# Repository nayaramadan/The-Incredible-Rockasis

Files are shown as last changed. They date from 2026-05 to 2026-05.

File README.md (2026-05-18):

# The-Incredible-Rockasis
CANClean is a roverthat finds, targets and, grabs empty soda cans. I t does this in order to keep your workspace clean and (less)messy.
# Pipeline
An ESP32-CAM takes live camera views and streams them via a TP-Link router(our Stasis Stash item) to my laptop where they are then sent out to roboflow for inference. After inference, the relative position of the can to the rover is calculted by my laptop andthe approach angle and vector are formed. The latop then sends these backto the rover where an Opheus Pico contols the motors to execute the vectors. The laptop then uses the sonar sensor and the camera to detect when the can is inside the claw. Then it closes.
# Demo
Demo
# Images
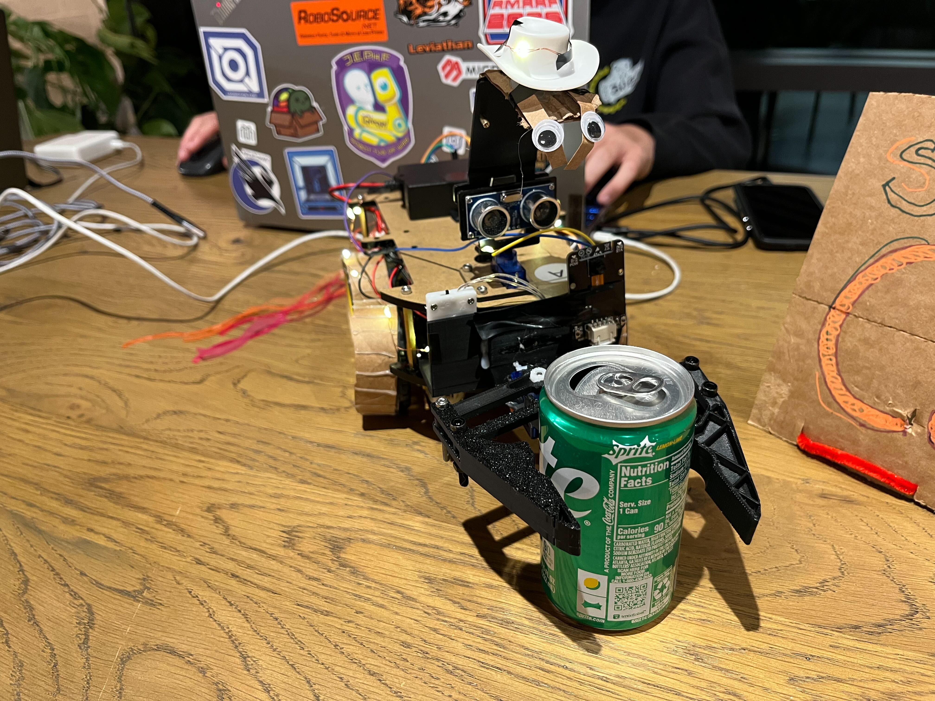
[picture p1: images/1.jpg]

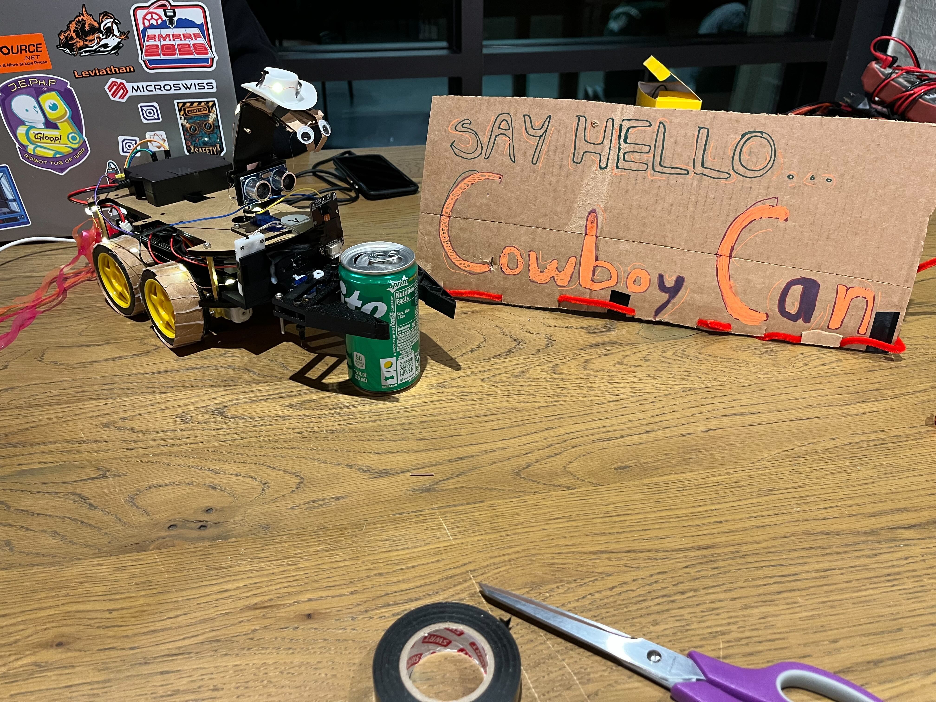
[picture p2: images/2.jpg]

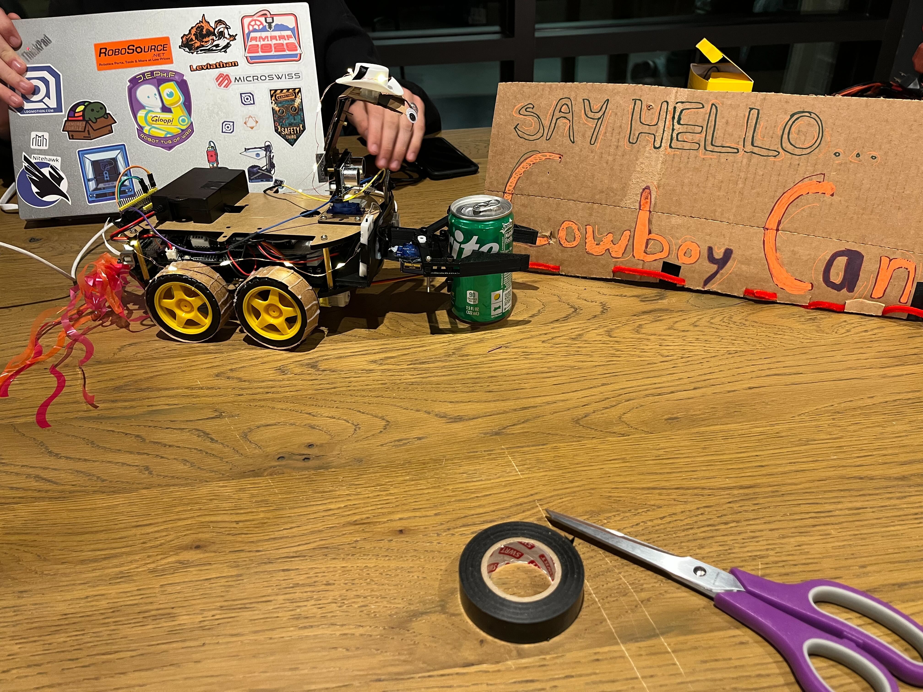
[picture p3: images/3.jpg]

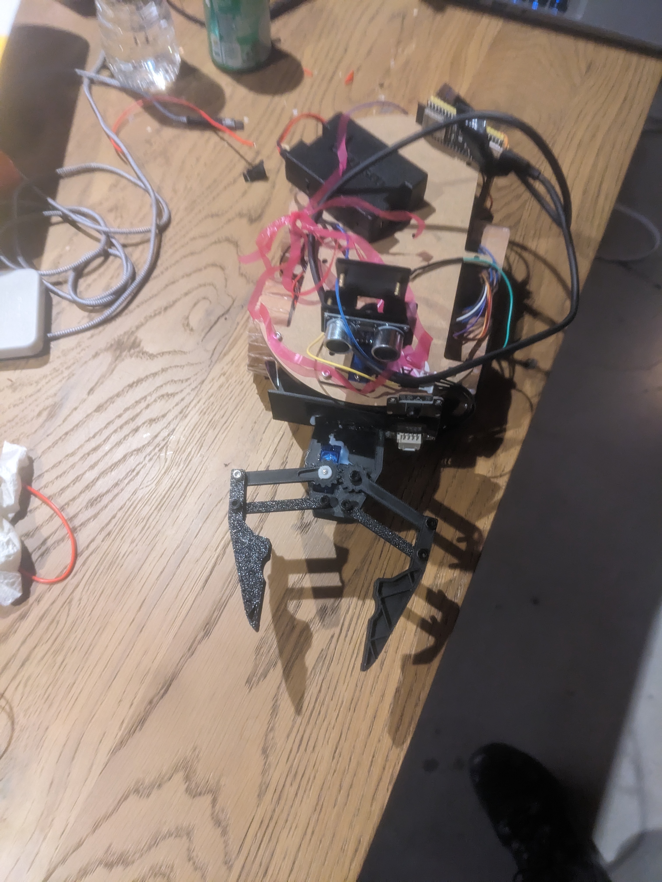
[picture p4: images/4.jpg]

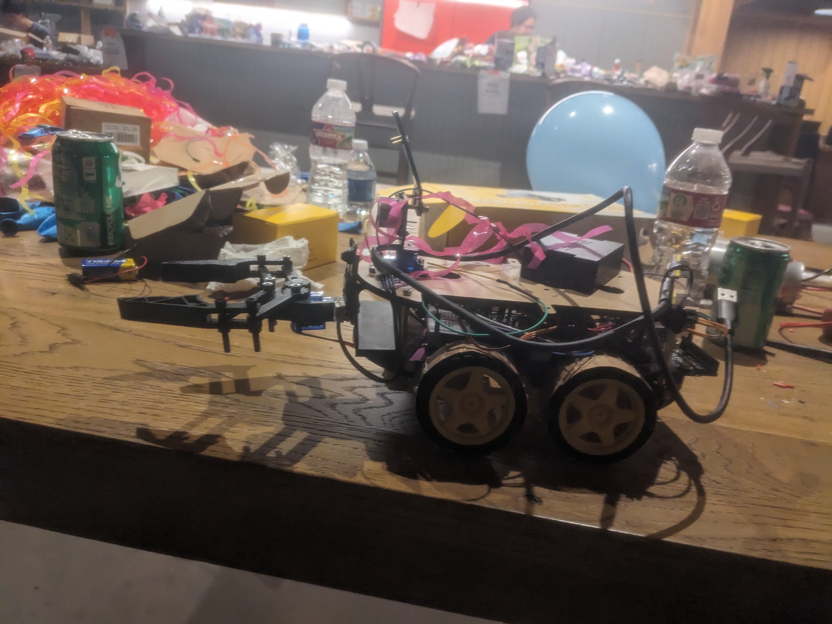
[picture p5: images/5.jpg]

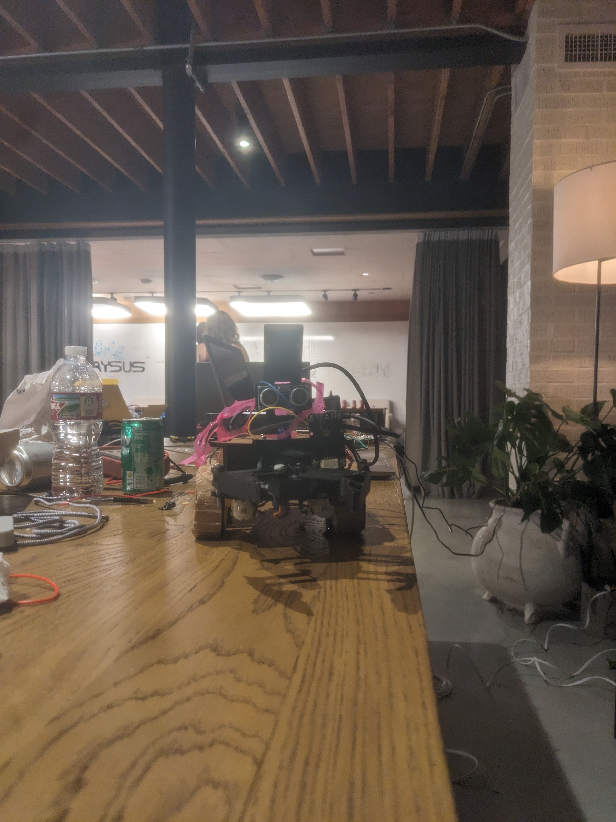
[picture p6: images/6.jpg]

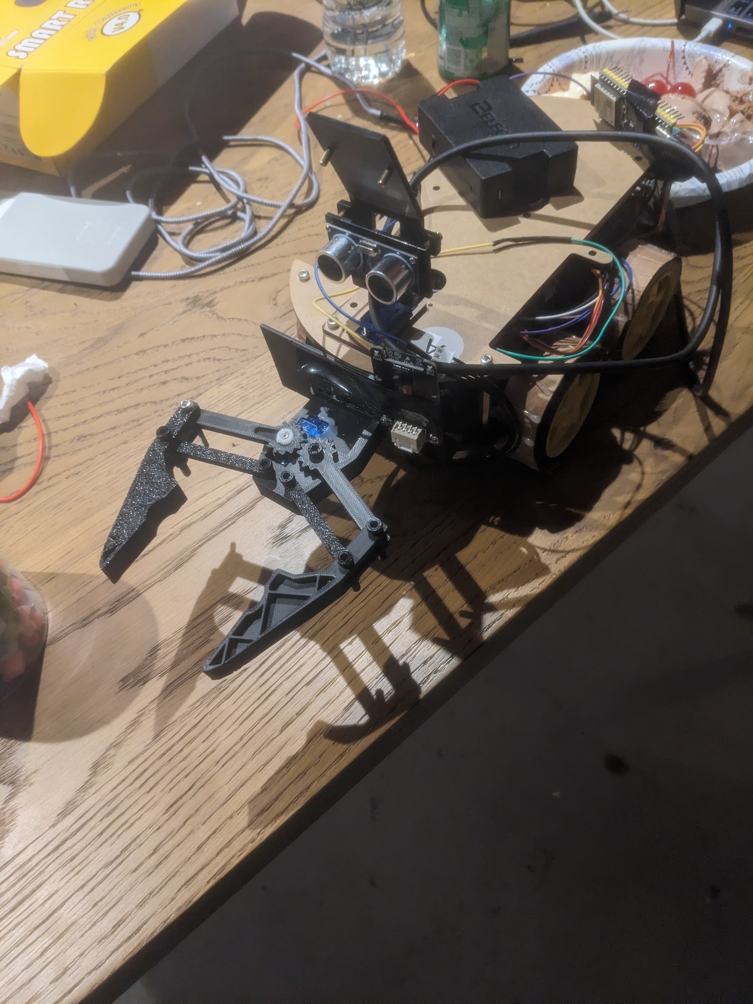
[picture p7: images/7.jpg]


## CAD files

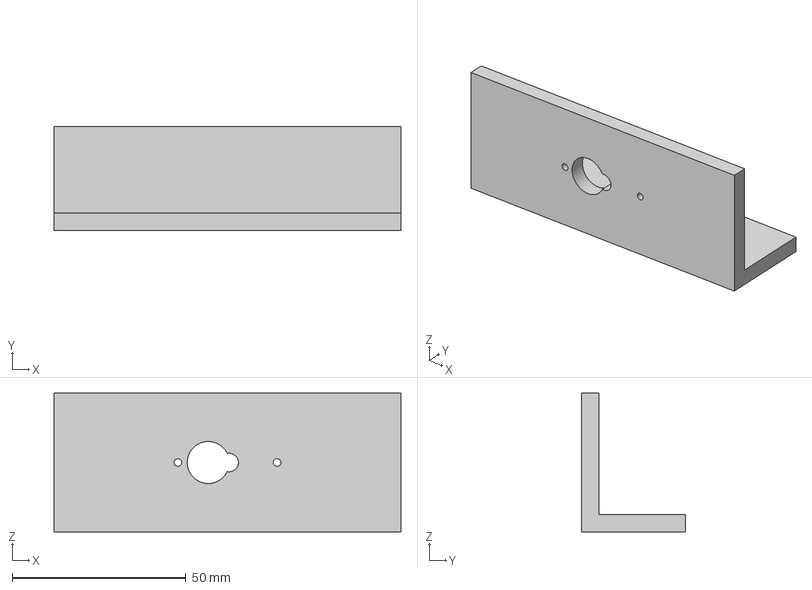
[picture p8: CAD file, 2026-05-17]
Body1.3mf
100.0 x 30.0 x 40.0 mm

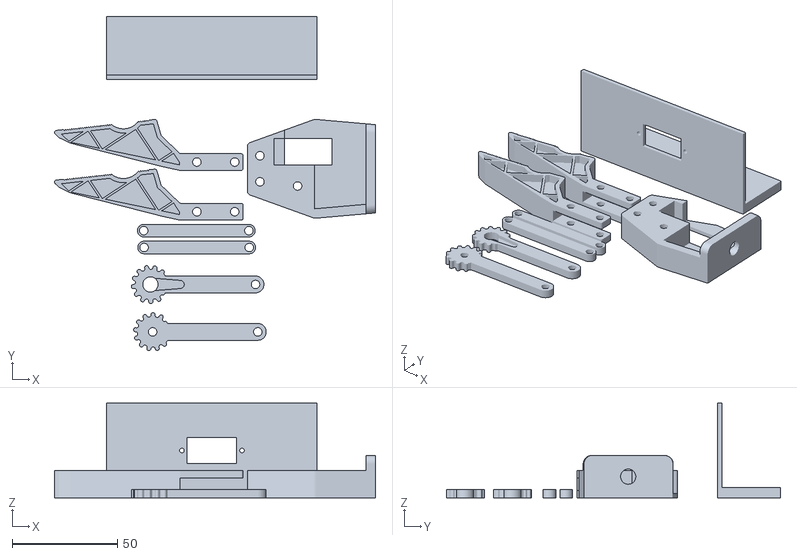
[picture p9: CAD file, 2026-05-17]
CAD/Base.stl
152.6 x 159.0 x 45.0

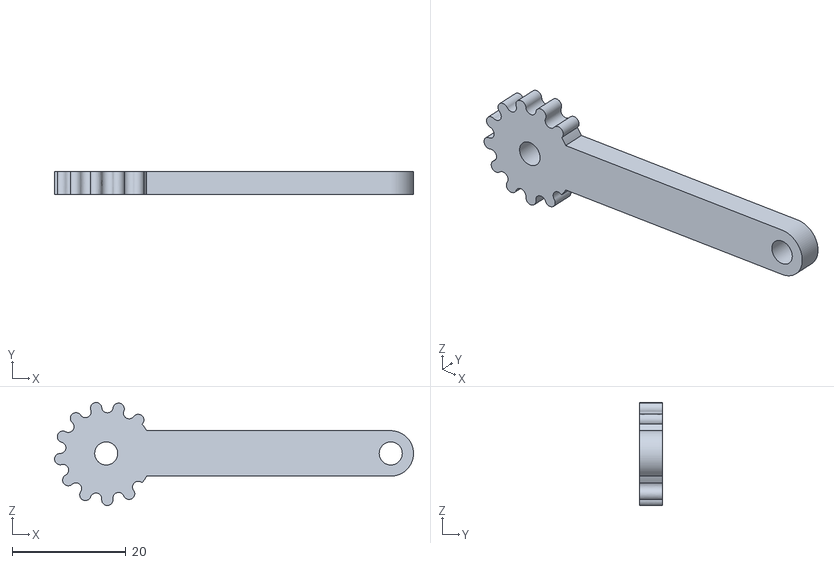
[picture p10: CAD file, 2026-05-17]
CAD/claw/Connector_Gear.stl
63.1 x 4.00 x 18.1

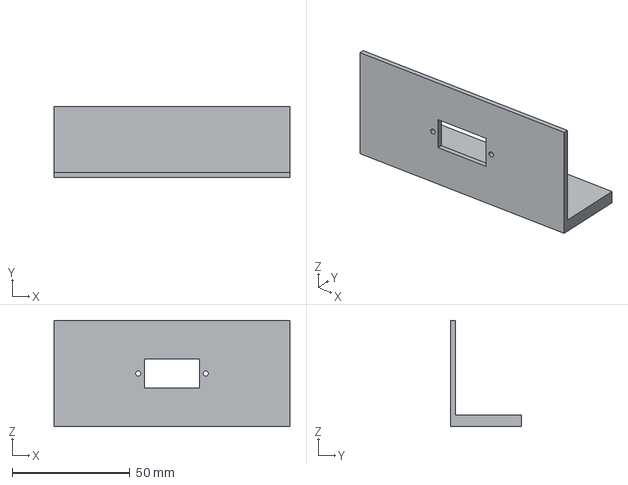
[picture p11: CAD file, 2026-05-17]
CAD/mount-Body.step
100.0 x 30.0 x 45.0 mm

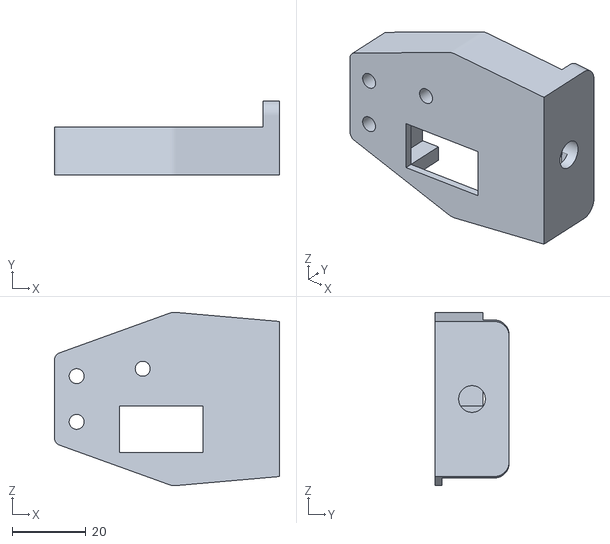
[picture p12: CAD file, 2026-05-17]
CAD/claw/Base.stl
60.9 x 20.1 x 46.9

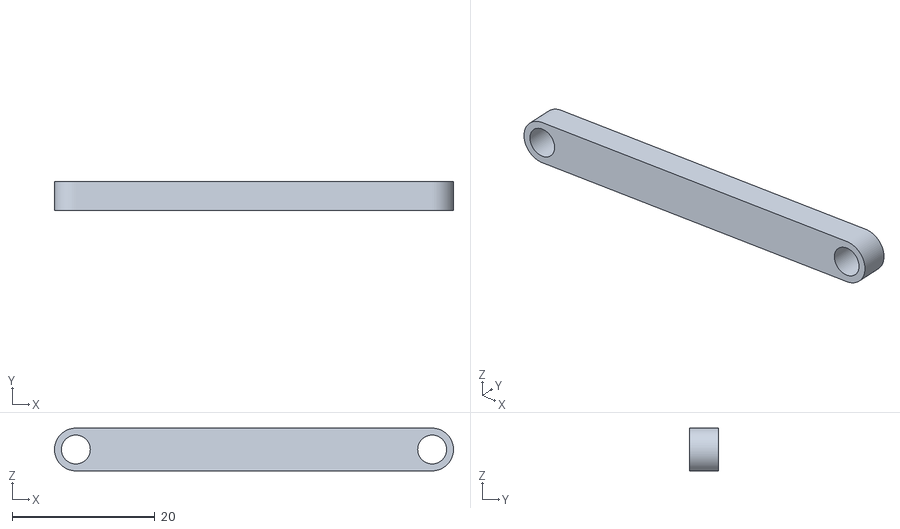
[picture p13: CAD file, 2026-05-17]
CAD/claw/Connector.stl
56.0 x 4.00 x 6.00

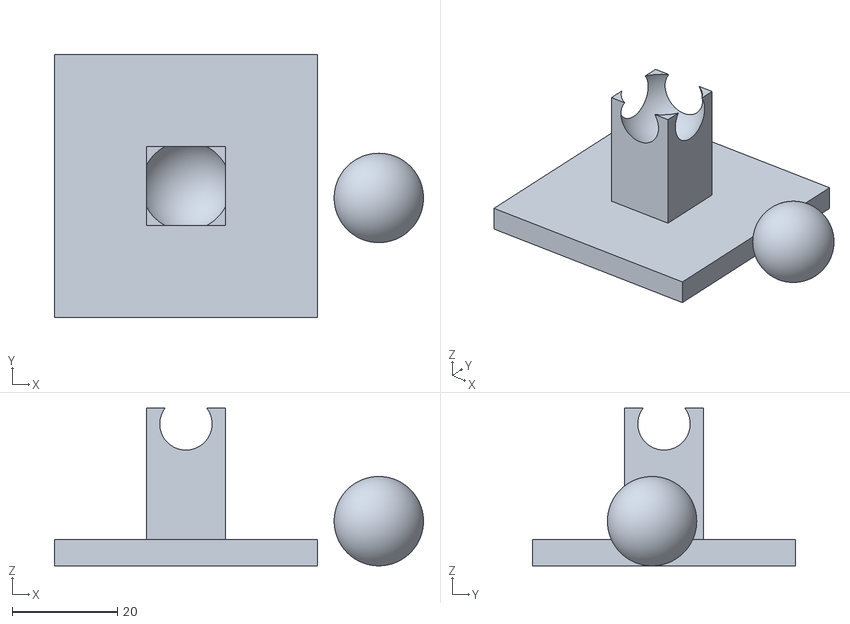
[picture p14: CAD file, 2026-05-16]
CAD/roller-and-mount.stl
70.2 x 50.0 x 30.0

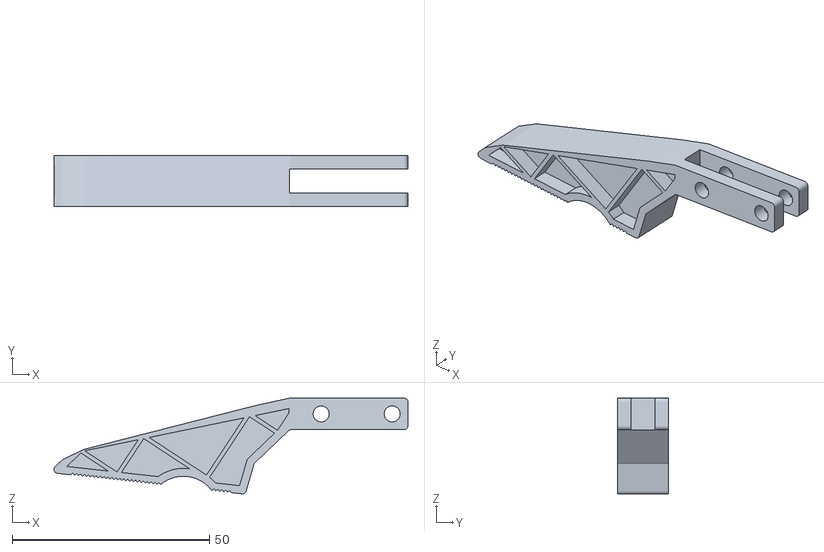
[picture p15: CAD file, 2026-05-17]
CAD/claw/Claw.stl
89.7 x 12.9 x 24.3

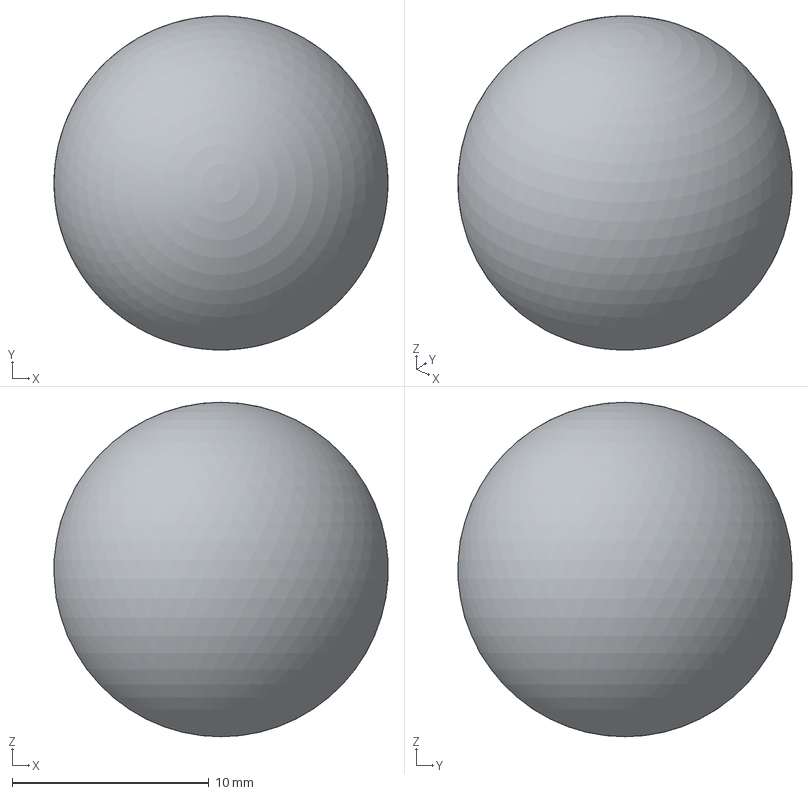
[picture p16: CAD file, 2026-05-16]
CAD/roller-Body.step
17.0 x 17.0 x 17.0 mm

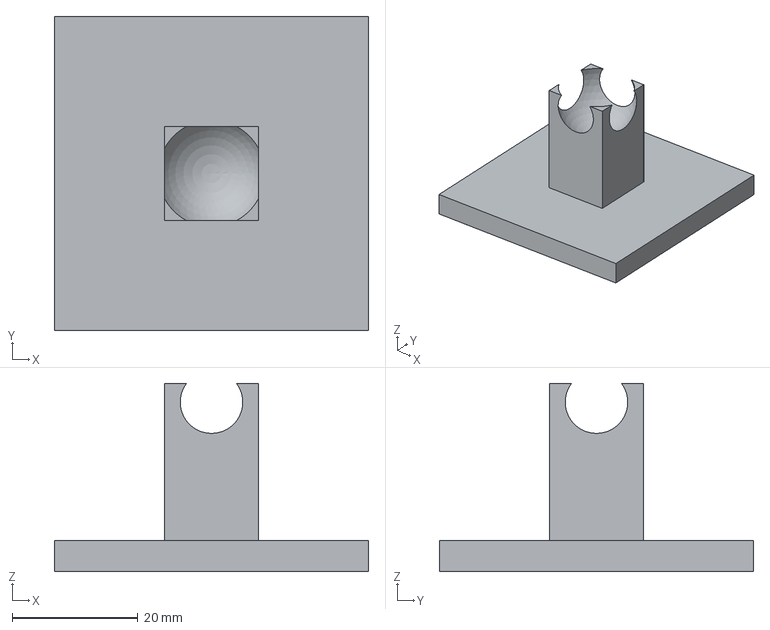
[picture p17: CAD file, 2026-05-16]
CAD/roller-mount-Body.step
50.0 x 50.0 x 30.0 mm

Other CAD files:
CAD/claw/Servo_Connector_Gear.stl
CAD/mount.FCStd

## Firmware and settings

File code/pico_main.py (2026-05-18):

"""
pico_main.py  –  Orpheus Pico (RP2040) rover firmware
======================================================
Responsibilities
  • Read MPU-6050 over I²C → complementary-filter roll/pitch/yaw
  • Drive 4× DC motors via TB6612FNG (2 ICs, 4 channels)
  • Control servo claw via hardware PWM
  • Receive COBS-framed command packets from ESP32-S3 over UART1
  • Send COBS-framed telemetry packets back to ESP32-S3

Wiring (edit PIN constants below to match your board)
─────────────────────────────────────────────────────
I²C (MPU-6050)
  SDA  → GP4      SCL → GP5      (I2C0)

UART (ESP32-S3)
  TX   → GP8      RX  → GP9      (UART1)  921600 baud

Single TB6612FNG motor driver
  STBY → GP16
  PWMA → GP10     AIN1 → GP11    AIN2 → GP12   (left motors – both wired to channel A)
  PWMB → GP13     BIN1 → GP14    BIN2 → GP15   (right motors – both wired to channel B)

Servo 1 (claw open/close)
  PWM  → GP28

Servo 2 (claw tilt / wrist)
  PWM  → GP27

Servo 3 (sonar yaw pan)
  PWM  → GP26

HC-SR04 (single sonar, direct to Pico)
  TRIG → GP19    ECHO → GP20
  ECHO needs a 1 kΩ/2 kΩ divider to 3.3 V if using a 5 V sensor board
"""

import struct
import time
import math
from machine import I2C, UART, Pin, PWM

# ─── Pin constants ────────────────────────────────────────────────────────────

I2C_SDA   = 4
I2C_SCL   = 5

UART_TX   = 8
UART_RX   = 9
UART_BAUD = 921600

# Single TB6612FNG
# Channel A → both left motors  (front-left + rear-left wired in parallel)
# Channel B → both right motors (front-right + rear-right wired in parallel)
M_STBY = 16
M_PWMA = 10
M_AIN1 = 11
M_AIN2 = 12
M_PWMB = 13
M_BIN1 = 14
M_BIN2 = 15

SERVO_PIN  = 28   # claw open/close
SERVO2_PIN = 27   # claw tilt / wrist
SERVO3_PIN = 26   # sonar yaw pan

# HC-SR04 (single, connected directly to Pico)
SONAR_TRIG = 19
SONAR_ECHO = 20
SONAR_TIMEOUT_US = 30_000   # 30 ms → ~5 m max range

# ─── MPU-6050 ─────────────────────────────────────────────────────────────────

MPU_ADDR  = 0x68
PWR_MGMT1 = 0x6B
ACCEL_OUT = 0x3B   # 6 bytes: AX_H AX_L AY_H AY_L AZ_H AZ_L
GYRO_OUT  = 0x43   # 6 bytes: GX_H GX_L GY_H GY_L GZ_H GZ_L
GYRO_CFG  = 0x1B   # ±250 °/s  → sensitivity 131 LSB/(°/s)
ACCEL_CFG = 0x1C   # ±2 g      → sensitivity 16384 LSB/g

GYRO_SENS  = 131.0
ACCEL_SENS = 16384.0

class MPU6050:
    def __init__(self, i2c):
        self.i2c = i2c
        # Wake the chip
        self.i2c.writeto_mem(MPU_ADDR, PWR_MGMT1, bytes([0x00]))
        time.sleep_ms(100)
        # Set gyro ±250 °/s, accel ±2 g
        self.i2c.writeto_mem(MPU_ADDR, GYRO_CFG,  bytes([0x00]))
        self.i2c.writeto_mem(MPU_ADDR, ACCEL_CFG, bytes([0x00]))

    def _read_raw(self, reg):
        raw = self.i2c.readfrom_mem(MPU_ADDR, reg, 6)
        vals = struct.unpack(">3h", raw)   # three signed 16-bit big-endian
        return vals

    def read_accel_g(self):
        ax, ay, az = self._read_raw(ACCEL_OUT)
        return ax / ACCEL_SENS, ay / ACCEL_SENS, az / ACCEL_SENS

    def read_gyro_dps(self):
        gx, gy, gz = self._read_raw(GYRO_OUT)
        return gx / GYRO_SENS, gy / GYRO_SENS, gz / GYRO_SENS


class ComplementaryFilter:
    """Simple roll/pitch/yaw complementary filter.
    Yaw integrates gyro only (no magnetometer), so it drifts slowly.
    """
    ALPHA = 0.96   # weight for gyro vs accel

    def __init__(self):
        self.roll  = 0.0
        self.pitch = 0.0
        self.yaw   = 0.0
        self._last_us = time.ticks_us()

    def update(self, ax, ay, az, gx, gy, gz):
        now = time.ticks_us()
        dt  = time.ticks_diff(now, self._last_us) * 1e-6
        self._last_us = now

        # Accel-derived angles
        roll_acc  = math.atan2(ay, az) * 57.2958
        pitch_acc = math.atan2(-ax, math.sqrt(ay*ay + az*az)) * 57.2958

        # Complementary blend
        self.roll  = self.ALPHA * (self.roll  + gx * dt) + (1 - self.ALPHA) * roll_acc
        self.pitch = self.ALPHA * (self.pitch + gy * dt) + (1 - self.ALPHA) * pitch_acc
        self.yaw  += gz * dt   # gyro-only; reset to 0 on boot

        return self.roll, self.pitch, self.yaw


# ─── Motor driver ─────────────────────────────────────────────────────────────

PWM_FREQ = 20_000   # 20 kHz – above audible range

class MotorChannel:
    """One half-bridge channel on a TB6612FNG."""
    def __init__(self, pwm_pin, in1_pin, in2_pin):
        self.pwm = PWM(Pin(pwm_pin), freq=PWM_FREQ, duty_u16=0)
        self.in1 = Pin(in1_pin, Pin.OUT)
        self.in2 = Pin(in2_pin, Pin.OUT)

    def set(self, speed: float):
        """speed: -1.0 … +1.0"""
        speed = max(-1.0, min(1.0, speed))
        duty  = int(abs(speed) * 65535)
        self.pwm.duty_u16(duty)
        if speed > 0:
            self.in1.value(1); self.in2.value(0)
        elif speed < 0:
            self.in1.value(0); self.in2.value(1)
        else:
            self.in1.value(0); self.in2.value(0)   # coast

    def brake(self):
        self.pwm.duty_u16(65535)
        self.in1.value(1); self.in2.value(1)


class RoverMotors:
    """
    Single TB6612FNG, two channels:
      Channel A → left side  (front-left + rear-left motors in parallel)
      Channel B → right side (front-right + rear-right motors in parallel)
    """
    def __init__(self):
        self.stby  = Pin(M_STBY, Pin.OUT, value=0)
        self.left  = MotorChannel(M_PWMA, M_AIN1, M_AIN2)
        self.right = MotorChannel(M_PWMB, M_BIN1, M_BIN2)
        self.enable()

    def enable(self):
        self.stby.value(1)

    def disable(self):
        self.stby.value(0)

    def drive(self, throttle: float, steering: float):
        """
        throttle: -1.0 (full reverse) … +1.0 (full forward)
        steering: -1.0 (full left)    … +1.0 (full right)
        Uses differential/tank mixing.
        """
        left  = max(-1.0, min(1.0, throttle - steering))
        right = max(-1.0, min(1.0, throttle + steering))
        self.left.set(left)
        self.right.set(right)

    def stop(self):
        self.left.set(0.0)
        self.right.set(0.0)


# ─── Servo ────────────────────────────────────────────────────────────────────

SERVO_FREQ      = 50          # 50 Hz = 20 ms period
SERVO_MIN_US    = 1000        # 1 ms  → fully open
SERVO_MAX_US    = 2000        # 2 ms  → fully closed
SERVO_CENTER_US = 1500

class ServoClaw:
    def __init__(self, pin):
        self.pwm = PWM(Pin(pin), freq=SERVO_FREQ)
        self.set(0.0)          # start centred / open

    def _us_to_duty(self, us):
        # RP2040 PWM period = 1/50 = 20 000 µs → 65535 counts
        return int(us / 20_000 * 65535)

    def set(self, pos: float):
        """pos: 0.0 = open, 1.0 = closed"""
        pos = max(0.0, min(1.0, pos))
        us  = int(SERVO_MIN_US + pos * (SERVO_MAX_US - SERVO_MIN_US))
        self.pwm.duty_u16(self._us_to_duty(us))

    def open(self):  self.set(0.0)
    def close(self): self.set(1.0)


# ─── HC-SR04 sonar ────────────────────────────────────────────────────────────

from machine import time_pulse_us

class HCSR04:
    """Single HC-SR04 ultrasonic sensor."""
    def __init__(self, trig_pin, echo_pin):
        self.trig = Pin(trig_pin, Pin.OUT, value=0)
        self.echo = Pin(echo_pin, Pin.IN)

    def distance_mm(self) -> int:
        """Returns distance in mm, or -1 on timeout / no echo."""
        self.trig.value(0)
        time.sleep_us(2)
        self.trig.value(1)
        time.sleep_us(10)
        self.trig.value(0)
        duration = time_pulse_us(self.echo, 1, SONAR_TIMEOUT_US)
        if duration < 0:
            return -1
        return int(duration * 0.1715)   # mm = µs × (343 000 mm/s / 2 / 1 000 000)


class SonarPan:
    """
    Combines the HC-SR04 with servo3 to sweep the sonar.
    Call update() every loop tick; it steps the servo and fires
    a ping at each position, building a simple scan buffer.
    """
    POSITIONS  = [0.0, 0.25, 0.5, 0.75, 1.0]   # 5 pan angles
    DWELL_MS   = 60    # ms to wait after moving before pinging

    def __init__(self, sonar: HCSR04, pan_servo: 'ServoClaw'):
        self.sonar     = sonar
        self.servo     = pan_servo
        self._idx      = 0
        self._moved_at = 0
        self._readings = [-1] * len(self.POSITIONS)
        # Move to first position immediately
        self.servo.set(self.POSITIONS[0])
        self._moved_at = time.ticks_ms()

    @property
    def readings(self) -> list:
        """Latest distance (mm) for each pan position. -1 = no echo."""
        return list(self._readings)

    @property
    def current_pos(self) -> float:
        """Current servo pan position 0.0–1.0."""
        return self.POSITIONS[self._idx]

    def update(self):
        """Call every loop iteration. Non-blocking step machine."""
        now = time.ticks_ms()
        if time.ticks_diff(now, self._moved_at) < self.DWELL_MS:
            return   # still settling
        # Ping at current position
        self._readings[self._idx] = self.sonar.distance_mm()
        # Advance to next position
        self._idx = (self._idx + 1) % len(self.POSITIONS)
        self.servo.set(self.POSITIONS[self._idx])
        self._moved_at = now


# ─── COBS framing ─────────────────────────────────────────────────────────────
# Consistent Overhead Byte Stuffing – zero-free framing over serial.
# Packet boundary = 0x00 byte.

def cobs_encode(data: bytes) -> bytes:
    out    = bytearray()
    code   = 1
    block  = bytearray()
    for byte in data:
        if byte == 0:
            out.append(code)
            out.extend(block)
            code  = 1
            block = bytearray()
        else:
            block.append(byte)
            code += 1
            if code == 0xFF:
                out.append(code)
                out.extend(block)
                code  = 1
                block = bytearray()
    out.append(code)
    out.extend(block)
    out.append(0x00)   # frame delimiter
    return bytes(out)


def cobs_decode(frame: bytes) -> bytes:
    """frame must NOT include the trailing 0x00 delimiter."""
    out = bytearray()
    i   = 0
    while i < len(frame):
        code = frame[i]
        i   += 1
        for _ in range(code - 1):
            if i >= len(frame):
                raise ValueError("COBS: truncated")
            out.append(frame[i])
            i += 1
        if code < 0xFF and i < len(frame):
            out.append(0x00)
    return bytes(out)


# ─── Packet formats  (little-endian structs) ──────────────────────────────────
#
# CMD packet  (ESP32-S3 → Pico)   10 bytes
#   [0]    packet type  0x01
#   [1]    throttle     int8  (-100 … +100, scale /100 → float)
#   [2]    steering     int8  (-100 … +100)
#   [3]    claw         uint8 (0 … 100)
#   [4]    servo2       uint8 (0 … 100)
#   [5]    servo3       uint8 (0 … 100)  sonar yaw pan
#   [6:10] CRC-32       uint32 LE (over bytes 0-5)
#
# TELEM packet (Pico → ESP32-S3)  20 bytes
#   [0]     packet type  0x02
#   [1:5]   roll         float32 LE
#   [5:9]   pitch        float32 LE
#   [9:13]  yaw          float32 LE
#   [13]    flags        uint8  (bit0=motors_on, bit1=claw_closed)
#   [14:16] sonar_mm     uint16 LE  (0xFFFF = no echo)
#   [16]    sonar_pan    uint8  (0-100, current servo3 position ×100)
#   [17:19] CRC-16       uint16 LE (over bytes 0-16)

CMD_TYPE   = 0x01
TELEM_TYPE = 0x02

def _crc16(data: bytes) -> int:
    crc = 0xFFFF
    for b in data:
        crc ^= b
        for _ in range(8):
            if crc & 1:
                crc = (crc >> 1) ^ 0xA001
            else:
                crc >>= 1
    return crc & 0xFFFF

def build_telem(roll, pitch, yaw, motors_on, claw_closed,
                sonar_mm: int, sonar_pan: float) -> bytes:
    flags    = (1 if motors_on else 0) | (2 if claw_closed else 0)
    sonar_v  = 0xFFFF if sonar_mm < 0 else min(0xFFFE, sonar_mm)
    pan_byte = max(0, min(100, int(sonar_pan * 100)))
    payload  = (struct.pack("<BfffB", TELEM_TYPE, roll, pitch, yaw, flags)
                + struct.pack("<HB", sonar_v, pan_byte))
    crc = _crc16(payload)
    return cobs_encode(payload + struct.pack("<H", crc))

def parse_cmd(raw: bytes):
    """Returns (throttle, steering, claw, servo2, servo3) or None."""
    if len(raw) < 10 or raw[0] != CMD_TYPE:
        return None
    import binascii
    crc_recv = struct.unpack("<I", raw[6:10])[0]
    crc_calc = binascii.crc32(raw[:6]) & 0xFFFFFFFF
    if crc_recv != crc_calc:
        return None
    throttle   = raw[1] / 100.0 if raw[1] < 128 else (raw[1] - 256) / 100.0
    steering   = raw[2] / 100.0 if raw[2] < 128 else (raw[2] - 256) / 100.0
    claw_pos   = raw[3] / 100.0
    servo2_pos = raw[4] / 100.0
    servo3_pos = raw[5] / 100.0
    return throttle, steering, claw_pos, servo2_pos, servo3_pos


# ─── Main loop ────────────────────────────────────────────────────────────────

def main():
    # Init hardware
    i2c   = I2C(0, sda=Pin(I2C_SDA), scl=Pin(I2C_SCL), freq=400_000)
    uart  = UART(1, baudrate=UART_BAUD, tx=Pin(UART_TX), rx=Pin(UART_RX),
                 rxbuf=256)

    imu    = MPU6050(i2c)
    filt   = ComplementaryFilter()
    motors = RoverMotors()
    claw   = ServoClaw(SERVO_PIN)
    servo2 = ServoClaw(SERVO2_PIN)
    servo3 = ServoClaw(SERVO3_PIN)   # sonar yaw pan

    sonar    = HCSR04(SONAR_TRIG, SONAR_ECHO)
    sonar_pan = SonarPan(sonar, servo3)

    rx_buf       = bytearray()
    telem_period = 20          # ms between telemetry packets (~50 Hz)
    last_telem   = time.ticks_ms()
    last_cmd_ms  = time.ticks_ms()
    CMD_TIMEOUT  = 500         # ms – stop motors if no command received

    claw_closed = False
    motors_on   = True

    print("Rover Pico firmware ready")

    while True:
        # ── Read UART (non-blocking) ──────────────────────────────────────────
        while uart.any():
            byte = uart.read(1)
            if byte == b'\x00':
                if rx_buf:
                    try:
                        raw    = cobs_decode(bytes(rx_buf))
                        result = parse_cmd(raw)
                        if result:
                            throttle, steering, claw_pos, servo2_pos, servo3_pos = result
                            motors.drive(throttle, steering)
                            claw.set(claw_pos)
                            servo2.set(servo2_pos)
                            # servo3 is driven by SonarPan automatically;
                            # only override if the PC explicitly commands a
                            # fixed pan position (servo3_pos >= 0 means override)
                            # Leave pan sweeping if servo3_pos == 0.5 (centre = no-op)
                            claw_closed = claw_pos > 0.5
                            last_cmd_ms = time.ticks_ms()
                    except Exception as e:
                        print("RX error:", e)
                    rx_buf = bytearray()
            else:
                rx_buf.extend(byte)

        # ── Command watchdog ──────────────────────────────────────────────────
        if time.ticks_diff(time.ticks_ms(), last_cmd_ms) > CMD_TIMEOUT:
            motors.stop()
            motors_on = False
        else:
            motors_on = True

        # ── Sonar pan sweep ───────────────────────────────────────────────────
        sonar_pan.update()

        # ── Read IMU + filter ─────────────────────────────────────────────────
        ax, ay, az = imu.read_accel_g()
        gx, gy, gz = imu.read_gyro_dps()
        roll, pitch, yaw = filt.update(ax, ay, az, gx, gy, gz)

        # ── Send telemetry ────────────────────────────────────────────────────
        now = time.ticks_ms()
        if time.ticks_diff(now, last_telem) >= telem_period:
            # Report the reading at the current pan position
            readings = sonar_pan.readings
            idx      = sonar_pan._idx
            dist_mm  = readings[idx] if readings else -1
            pkt = build_telem(roll, pitch, yaw, motors_on, claw_closed,
                              dist_mm, sonar_pan.current_pos)
            uart.write(pkt)
            last_telem = now

        time.sleep_us(500)


if __name__ == "__main__":
    main()

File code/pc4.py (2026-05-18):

"""
rover_pc.py  –  PC rover controller with TUI
=============================================
Connects to the ESP32-S3 over TCP (WiFi) for telemetry and commands.
Optionally reads joystick/button data from the ESP32-C3-mini over USB serial.

NEW: Servo2 (wrist) and Servo3 (pan) keyboard controls.

Usage
─────
  pip install pyserial
  python rover_pc.py --rover 192.168.1.42

  # With C3-mini joystick controller:
  python rover_pc.py --rover 192.168.1.42 --controller /dev/ttyUSB0
  python rover_pc.py --rover 192.168.1.42 --controller auto

  # Keyboard-only (no C3):
  python rover_pc.py --rover 192.168.1.42

TUI controls (keyboard always active, even with joystick connected)
─────────────────────────────────────────────────────────────────────
  W / S        throttle +/-
  A / D        steering left/right
  Space        full stop (throttle + steering → 0)
  C            toggle claw open/close
  E / R        servo2 (wrist) -/+
  T / Y        servo3 (pan)   -/+
  Q / Escape   quit

  Arrow keys   same as WASD
  R            reset yaw to 0 (local display only)

Packet spec (must match firmware)
──────────────────────────────────
CMD  10 bytes  type=0x01 | throttle int8×100 | steering int8×100 |
               claw u8×100 | servo2 u8×100 | servo3 u8×100 | CRC32 LE
TELEM 17 bytes type=0x02 | roll f32 | pitch f32 | yaw f32 | flags u8 |
               sonar u16 | pan u8×100
TCP framing: 2-byte LE length prefix + payload
"""

import argparse
import binascii
import curses
import queue
import socket
import struct
import sys
import threading
import time
from dataclasses import dataclass, field
from typing import Optional

try:
    import serial
    import serial.tools.list_ports
except ImportError:
    sys.exit("pyserial not found – run:  pip install pyserial")

# ─── Packet spec constants ────────────────────────────────────────────────────

CMD_TYPE   = 0x01
TELEM_TYPE = 0x02
TELEM_LEN  = 17   # FIXED: was 19, now matches Pico payload length
CMD_LEN    = 10

# ─── CRC ──────────────────────────────────────────────────────────────────────

def crc16(data: bytes) -> int:
    crc = 0xFFFF
    for b in data:
        crc ^= b
        for _ in range(8):
            crc = (crc >> 1) ^ 0xA001 if crc & 1 else crc >> 1
    return crc & 0xFFFF

# ─── CMD builder ──────────────────────────────────────────────────────────────

def build_cmd(throttle: float, steering: float, claw: float,
              servo2: float = 0.5, servo3: float = 0.5) -> bytes:
    t  = max(-100, min(100, int(throttle * 100))) & 0xFF
    s  = max(-100, min(100, int(steering * 100))) & 0xFF
    c  = max(0, min(100, int(claw   * 100)))
    s2 = max(0, min(100, int(servo2 * 100)))
    s3 = max(0, min(100, int(servo3 * 100)))
    payload = bytes([CMD_TYPE, t, s, c, s2, s3])
    crc = binascii.crc32(payload) & 0xFFFFFFFF
    return payload + struct.pack("<I", crc)

def frame_cmd(throttle, steering, claw, servo2=0.5, servo3=0.5) -> bytes:
    """Length-prefix a CMD payload for TCP."""
    payload = build_cmd(throttle, steering, claw, servo2, servo3)
    return struct.pack("<H", len(payload)) + payload

# ─── TELEM parser ─────────────────────────────────────────────────────────────

@dataclass
class Telemetry:
    roll:      float = 0.0
    pitch:     float = 0.0
    yaw:       float = 0.0
    motors_on: bool  = False
    claw_cl:   bool  = False
    sonar_mm:  int   = -1
    pan:       float = 0.5
    age:       float = field(default_factory=time.monotonic)

    @property
    def sonar_str(self) -> str:
        return "---" if self.sonar_mm < 0 else f"{self.sonar_mm} mm"

    @property
    def stale(self) -> bool:
        return (time.monotonic() - self.age) > 1.0

def parse_telem(data: bytes) -> Optional[Telemetry]:
    if len(data) < TELEM_LEN or data[0] != TELEM_TYPE:
        return None
    # No embedded CRC – integrity guaranteed by framing layer (FrameDecoder on S3)
    _, roll, pitch, yaw, flags = struct.unpack_from("<BfffB", data)
    sonar_v  = struct.unpack_from("<H", data, 14)[0]
    pan_byte = data[16]
    return Telemetry(
        roll      = roll,
        pitch     = pitch,
        yaw       = yaw,
        motors_on = bool(flags & 0x01),
        claw_cl   = bool(flags & 0x02),
        sonar_mm  = -1 if sonar_v == 0xFFFF else sonar_v,
        pan       = pan_byte / 100.0,
    )

# ─── Rover TCP connection ─────────────────────────────────────────────────────

class RoverLink:
    """
    Background thread that maintains the TCP connection to the S3.
    Thread-safe send() and latest telem via .telem property.
    """
    def __init__(self, host: str, port: int = 5005):
        self.host       = host
        self.port       = port
        self.telem      = Telemetry()
        self._sock      = None
        self._lock      = threading.Lock()
        self._send_q    = queue.Queue(maxsize=10)
        self._stop      = threading.Event()
        self._connected = threading.Event()
        self.rx_count   = 0
        self._t0        = time.monotonic()

    @property
    def hz(self) -> float:
        elapsed = time.monotonic() - self._t0
        return self.rx_count / elapsed if elapsed > 0 else 0.0

    @property
    def connected(self) -> bool:
        return self._connected.is_set()

    def start(self):
        threading.Thread(target=self._run, daemon=True).start()

    def stop(self):
        self._stop.set()

    def send(self, throttle, steering, claw, servo2=0.5, servo3=0.5):
        """Queue a CMD frame.  Non-blocking; drops if queue full."""
        try:
            self._send_q.put_nowait(
                frame_cmd(throttle, steering, claw, servo2, servo3))
        except queue.Full:
            pass

    def _run(self):
        rx_buf = bytearray()
        while not self._stop.is_set():
            # ── Connect ───────────────────────────────────────────────────────
            try:
                s = socket.socket(socket.AF_INET, socket.SOCK_STREAM)
                s.settimeout(5.0)
                s.connect((self.host, self.port))
                s.settimeout(0.05)
                with self._lock:
                    self._sock = s
                self._connected.set()
                rx_buf = bytearray()
            except OSError:
                self._connected.clear()
                time.sleep(2)
                continue

            # ── IO loop ───────────────────────────────────────────────────────
            while not self._stop.is_set():
                # TX
                while not self._send_q.empty():
                    try:
                        frame = self._send_q.get_nowait()
                        with self._lock:
                            if self._sock:
                                self._sock.sendall(frame)
                    except (queue.Empty, OSError):
                        break
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

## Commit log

2026-05-16 add roller cad
    [roller-Body.step, roller-mount-Body.step]
2026-05-16 add combo stl
    [roller-and-mount.stl]
